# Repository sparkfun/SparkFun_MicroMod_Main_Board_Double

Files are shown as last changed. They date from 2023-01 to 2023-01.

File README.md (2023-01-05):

SparkFun MicroMod Main Board - Double
========================================

SparkFun MicroMod Main Board - Double (https://www.sparkfun.com/products/20595)

[*SparkFun MicroMod Main Board - Double (DEV-20595)*](https://www.sparkfun.com/products/20595)

The MicroMod Main Board - Double is a specialized carrier board that allows you to interface a MicroMod Processor Board with up to two MicroMod Function Boards. With the M.2 MicroMod connector, connecting your Processor and Function Boards is a breeze. Simply match up the key on your board's beveled edge connector to the key on the M.2 connector and secure the boards with screws.

The Double Main Board includes one USB-C connector for power and programming the Processor Board. A jumper is available on the back of the board to isolate the USB C's shield pin. Two buttons for reset and boot are also populated on the board. Processor Board pins are also broken out as 2x5 SWD pins. Also, included on the board is a 2A resettable fuse and 3.3V/1A voltage regulator. A second 3.3V/500mA voltage regulator is included on the board to power your Qwiic-enabled devices. We've even added convenient PTH jumpers for advanced users looking to bypass the fuse and measure the current consumption on the 5V and 3.3V lines for low-power testing. For those that need to go remote with their application, the board includes a 2-pin JST connector and a single-cell LiPo MCP73831 charge IC (set to a charge rate of 500mA).

Two switches have been included to toggle between the general-purpose pins and each Function Board's voltage regulator. A third switch has also been included to switch between different SPI chip select pins on the second Function Board. Four status LEDs are available for power and charging. These can also be disabled through the jumpers. There is a microSD card socket so you can also plug in a microSD card for data logging. The microSD socket can be disabled through the I/O pins. Finally, two Qwiic connectors are populated on the board with built-in pull-up resistors to easily add Qwiic-enabled I<sup>2</sup>C devices to your projects!

Repository Contents
-------------------

* **/Firmware** - Arduino example code from the tutorial
* **/Hardware** - Eagle design files (.brd, .sch)
* **/Production** - Production panel files (.brd)

Documentation
--------------

* **[Hookup Guide V2](https://learn.sparkfun.com/tutorials/2683)** - Basic hookup guide

Product Versions
----------------
* [DEV-20595](https://www.sparkfun.com/products/20595)- Initial release, v2.2
* [DEV-18576](https://www.sparkfun.com/products/18576)- Initial release, v1.1

Version History
---------------
* v2.2
* v1.1 - Initial Release

License Information
-------------------

This product is _**open source**_! 

Please review the LICENSE.md file for license information. 

If you have any questions or concerns on licensing, please contact technical support on our [SparkFun forums](https://forum.sparkfun.com/viewforum.php?f=152).

Distributed as-is; no warranty is given.

- Your friends at SparkFun.

_<COLLABORATION CREDIT>_

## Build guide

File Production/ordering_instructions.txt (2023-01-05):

panel size, 139x250mm
PCB thickness, 1.6mm
number of layers, 2
soldermask color, Red
silkscreen color, White
oz copper, 1oz
finish, HASL lead free
stencils, top
pcs per panel, 3
min trace width, 0.1778mm / 0.0070in
min drill size, 0.3048mm / 0.0120in

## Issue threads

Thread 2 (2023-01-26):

CAN-RX and CAN-TX Labels are reversed on MICROMOD_FUNCTION symbol

NPoole, 2023-01-26:
As it's currently labeled, this board appears to connect the processor board's CAN-RX to the function board's CAN-TX and vise versa, but this is incorrect. I've updated the library symbol in the Eagle library to fix the labels without changing the wiring. Next time this board gets revved, replace MICROMOD_FUNCTION_MAIN with the new version and replace pins "by coordinates" (not "by names") in order to ensure the schematic is fixed.

To reiterate, the correct connection scheme is TX-TX and RX-RX

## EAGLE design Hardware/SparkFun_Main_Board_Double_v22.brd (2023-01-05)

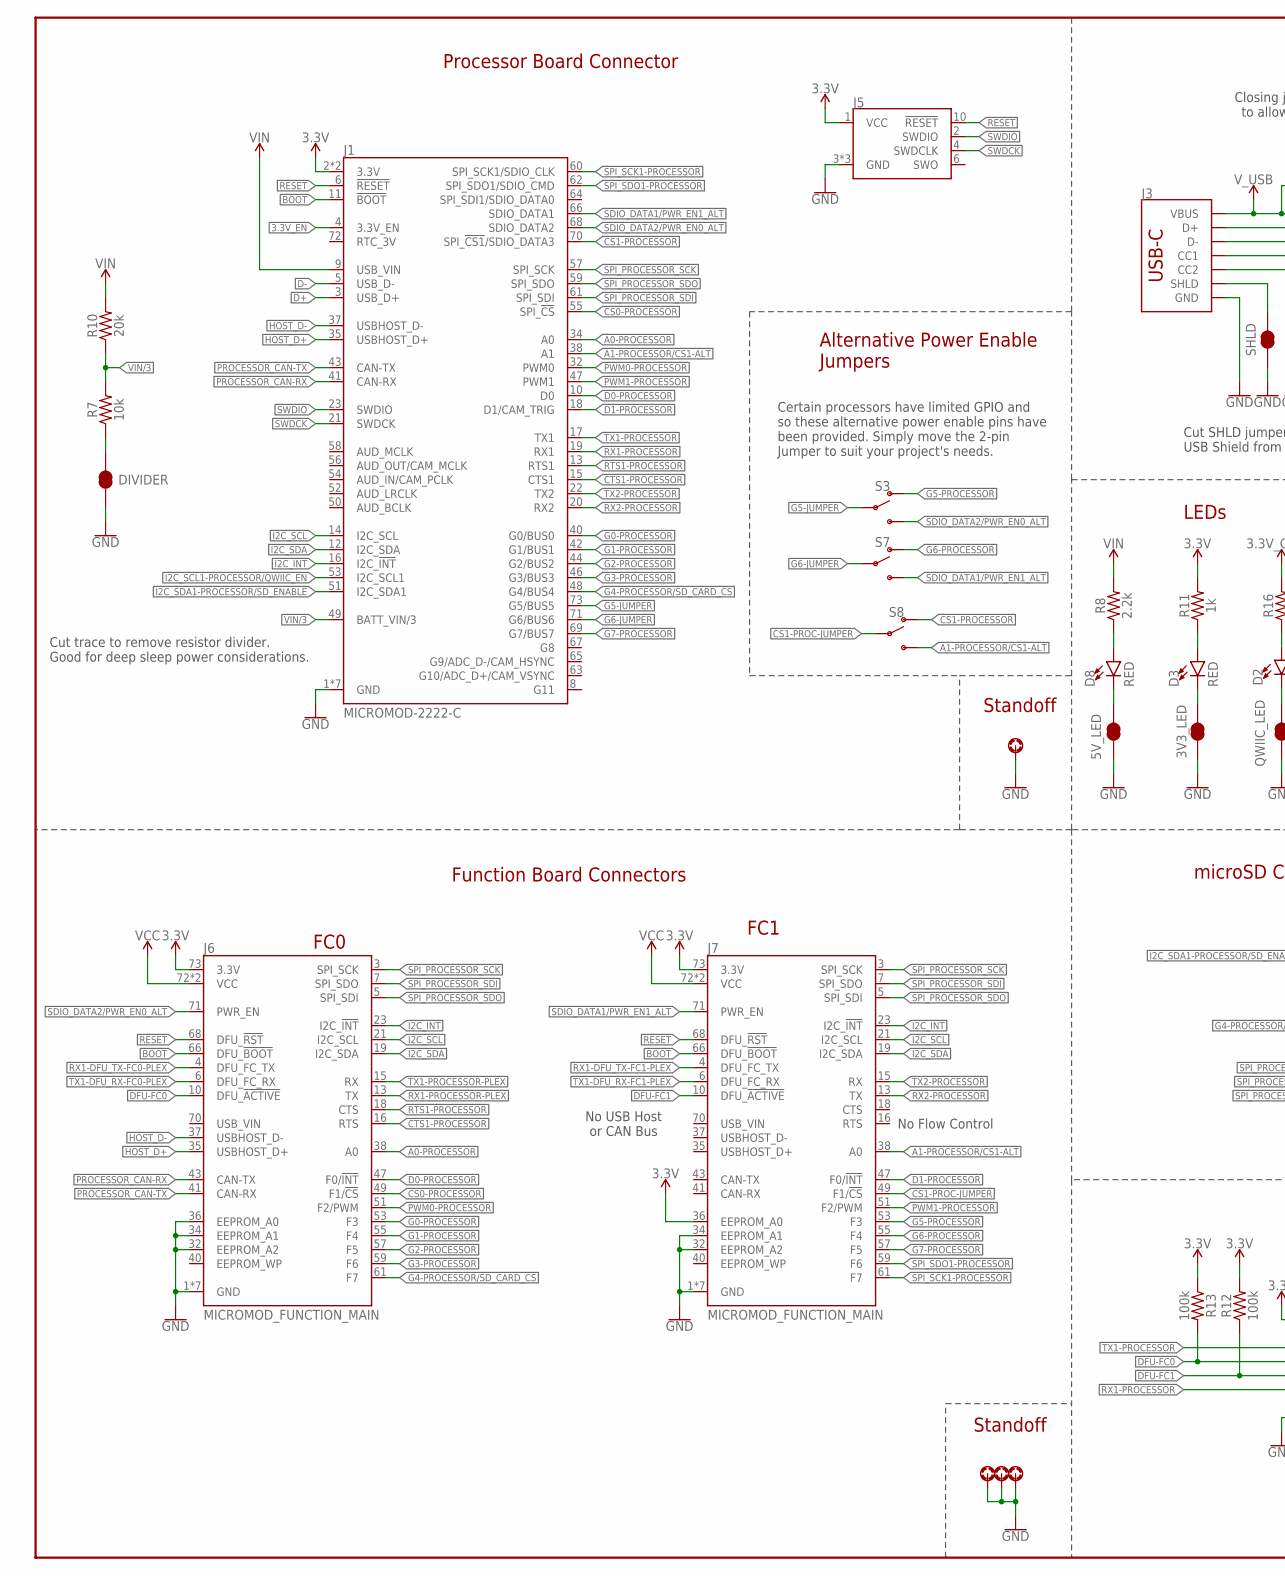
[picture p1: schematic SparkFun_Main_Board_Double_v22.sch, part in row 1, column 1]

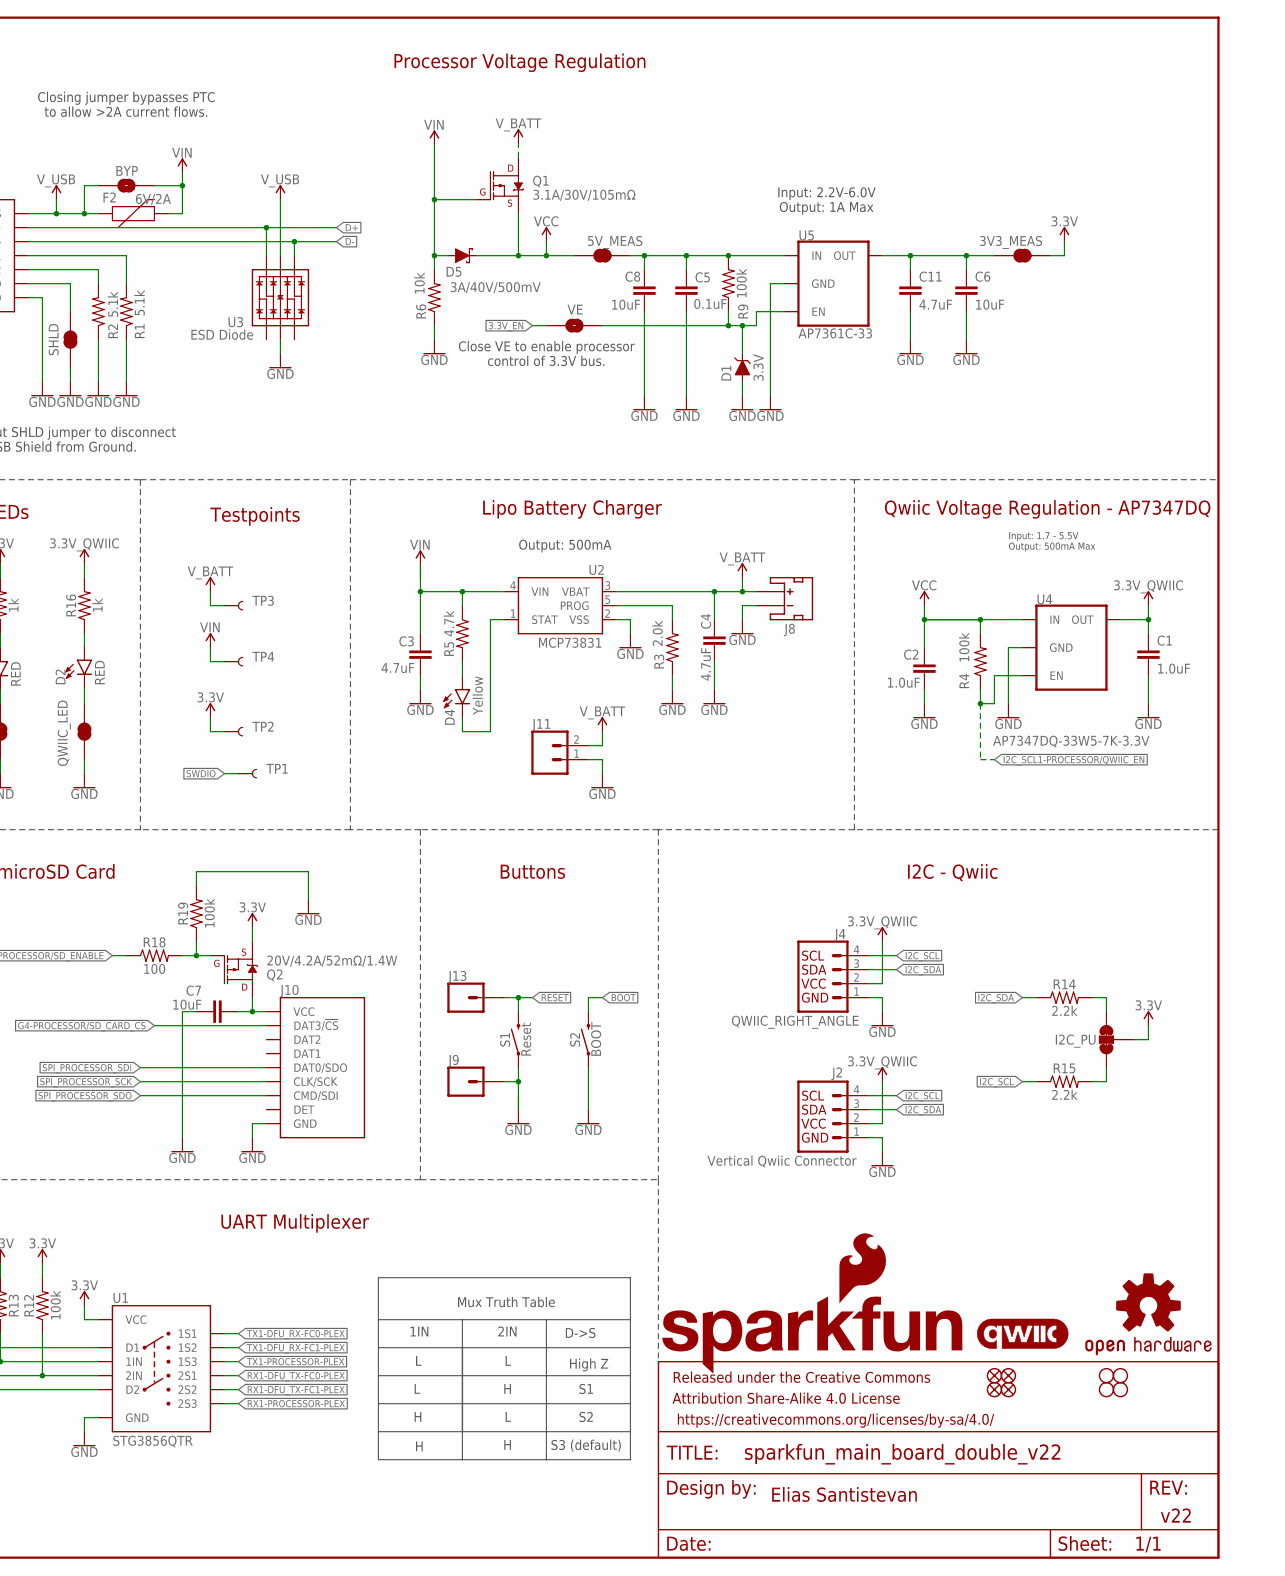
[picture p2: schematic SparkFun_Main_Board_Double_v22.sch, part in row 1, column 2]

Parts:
3V3_LED, 5V_LED: JUMPER-SMT_2_NC_TRACE_SILK; SMT-JUMPER_2_NC_TRACE_SILK
3V3_MEAS, 5V_MEAS: JUMPER-COMBO_2_NC_TRACE; COMBO-JUMPER_2_NC_TRACE
BYP: JUMPER-SMT_2_NO_SILK; SMT-JUMPER_2_NO_SILK
C1, C2: 1.0uF; 0603
C3, C4, C11: 4.7uF; 0603
C5: 0.1uF; 0603
C6, C8: 10uF; 0805
C7: 10uF; 0603
D1: 3.3V; SOD-323
D2, D3, D8: RED; LED-0603
D4: Yellow; LED-0603
D5: 3A/40V/500mV; SMA-DIODE
DIVIDER: JUMPER-SMT_2_NC_TRACE_SILK; SMT-JUMPER_2_NC_TRACE_SILK
F2: 6V/2A; 1210
FD1, FD2, FD3, FD4: FIDUCIAL1X2; FIDUCIAL-1X2
FRAME1: FRAME-LEDGER; CREATIVE_COMMONS
H2, H3, H4, H8: STAND-OFF-REFLOW-M2.5_2.5MM_TALL; STAND-OFF-REFLOW-M2.5
H14, H15, H16, H17: STAND-OFFTIGHT; STAND-OFF-TIGHT
I2C_PU: JUMPER-SMT_3_2-NC_TRACE_SILK; SMT-JUMPER_3_2-NC_TRACE_SILK
J1: MICROMOD-2222-C; M.2-CONNECTOR-E
J2: Vertical Qwiic Connector; JST04_1MM_VERT
J3: USB_C_2-LAYER_PADS; USB-C-16P-2LAYER-PADS
J4: QWIIC_RIGHT_ANGLE; JST04_1MM_RA
J5: CORTEX_JTAG_DEBUG_MINIMUM_PTH; 2X5-PTH-1.27MM
J6, J7: MICROMOD_FUNCTION_MAIN; M.2-CONNECTOR-E-FUNCTION-STANDARD
J8: JST_2MM_MALE; JST-2-SMD
J9, J13: CONN_01PTH_NO_SILK_YES_STOP; 1X01_NO_SILK
J10: MICRO-SD-PUSH-PUSH-EXT-PIN; MICROSD-EXTERNALPIN
J11: CONN_021X02_NO_SILK; 1X02_NO_SILK
LOGO1: QWIIC_LOGO_8MM; QWIIC_8MM
LOGO2: SFE_LOGO_NAME_FLAME.3_INCH; SFE_LOGO_NAME_FLAME_.3
LOGO3: OSHW-LOGOL; OSHW-LOGO-L
Q1: 3.1A/30V/105mΩ; SOT23-3
Q2: 20V/4.2A/52mΩ/1.4W; SOT23-3
QWIIC_LED: JUMPER-SMT_2_NC_TRACE_SILK; SMT-JUMPER_2_NC_TRACE_SILK
R1, R2: 5.1k; 0603
R3: 2.0k; 0603
R4, R9, R12, R13, R19: 100k; 0603
R5: 4.7k; 0603
R6, R7: 10k; 0603
R8, R14, R15: 2.2k; 0603
R10: 20k; 0603
R11, R16: 1k; 0603
R18: 100; 0603
S1: Reset; TACTILE_SWITCH_SMD_5.2MM
S2: BOOT; TACTILE_SWITCH_SMD_5.2MM
S3, S7, S8: SWITCH-SPDT-SMD-RIGHT-ANGLE; SWITCH_SPST_SMD_A
SHLD: JUMPER-SMT_2_NC_TRACE_SILK; SMT-JUMPER_2_NC_TRACE_SILK
TP1, TP2, TP3, TP4: TEST-POINT3X5; PAD.03X.05
U1: STG3856QTR; STG3856
U2: MCP73831; SOT23-5
U3: ESD Diode; SOT-23-6
U4: AP7347DQ-33W5-7K-3.3V; SOT25
U5: AP7361C-33; UDFN-8
VE: JUMPER-SMT_2_NO_SILK; SMT-JUMPER_2_NO_SILK

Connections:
3.3V: 3V3_MEAS.2, 3V3_MEAS.4 (2), I2C_PU.2, J1.2 (3.3V), J1.74 (3.3V), J5.1 (VCC), J6.73 (3.3V), J7.36 (EEPROM_A0), J7.73 (3.3V), Q2.2 (S), R11.2, R12.2, R13.1, TP2.1, U1.P11 (VCC)
3.3V_EN: J1.4 (3.3V_EN), VE.1
3.3V_EN_VE: D1.C, R9.1, U5.5 (EN), VE.2
3.3V_QWIIC: C1.1, J2.2, J4.2, R16.2, U4.5 (OUT)
3V3_MEAS: 3V3_MEAS.1, 3V3_MEAS.3 (1), C6.1, C11.1, U5.1 (OUT)
5V_MEAS: 5V_MEAS.2, 5V_MEAS.4 (2), C5.1, C8.1, R9.2, U5.8 (IN)
!BOOT!: J1.11 (!BOOT!), J6.66 (DFU_!BOOT!), J7.66 (DFU_!BOOT!), S2.3 (2), S2.4 (2)
!CS0!-PROCESSOR: J1.55 (SPI_!CS!), J6.49 (F1/!CS!)
!CS1!-PROC-JUMPER: J7.49 (F1/!CS!), S8.2
!CS1!-PROCESSOR: J1.70 (SPI_!CS1!/SDIO_DATA3), S8.1 (O)
!DFU-FC0!: J6.10 (DFU_!ACTIVE!), R13.2, U1.P12 (1IN)
!DFU-FC1!: J7.10 (DFU_!ACTIVE!), R12.1, U1.P10 (2IN)
!RESET!: J1.6 (!RESET!), J5.10 (!RESET), J6.68 (DFU_!RST!), J7.68 (DFU_!RST!), J13.1, S1.3 (2), S1.4 (2)
A0-PROCESSOR: J1.34 (A0), J6.38 (A0)
A1-PROCESSOR/!CS1!-ALT: J1.38 (A1), J7.38 (A0), S8.3 (S)
CTS1-PROCESSOR: J1.15 (CTS1), J6.16 (RTS)
D0-PROCESSOR: J1.10 (D0), J6.47 (F0/!INT!)
D1-PROCESSOR: J1.18 (D1/CAM_TRIG), J7.47 (F0/!INT!)
D+: J1.3 (USB_D+), J3.A6 (D+), J3.B6 (D+), U3.6 (IO4)
D-: J1.5 (USB_D-), J3.A7 (D-), J3.B7 (D-), U3.4 (IO3)
G0-PROCESSOR: J1.40 (G0/BUS0), J6.53 (F3)
G1-PROCESSOR: J1.42 (G1/BUS1), J6.55 (F4)
G2-PROCESSOR: J1.44 (G2/BUS2), J6.57 (F5)
G3-PROCESSOR: J1.46 (G3/BUS3), J6.59 (F6)
G4-PROCESSOR/SD_CARD_!CS!: J1.48 (G4/BUS4), J6.61 (F7), J10.2 (DAT3/!CS!)
G5-JUMPER: J1.73 (G5/BUS5), S3.2
G5-PROCESSOR: J7.53 (F3), S3.1 (O)
G6-JUMPER: J1.71 (G6/BUS6), S7.2
G6-PROCESSOR: J7.55 (F4), S7.1 (O)
G7-PROCESSOR: J1.69 (G7/BUS7), J7.57 (F5)
GND: 3V3_LED.1, 5V_LED.1, C1.2, C2.2, C3.2, C4.2, C5.2, C6.2, C7.1, C8.2, C11.2, D1.A, DIVIDER.1, H2.1, H3.1, H4.1, H8.1, J1.1 (GND), J1.7 (GND), J1.33 (GND), J1.36 (GND), J1.39 (GND), J1.45 (GND), J1.75 (GND), J2.1, J3.GND, J3.GND2 (GND), J4.1, J5.3 (GND), J5.5 (GND), J5.9 (GND), J6.1 (GND), J6.2 (GND), J6.8 (GND), J6.32 (EEPROM_A2), J6.33 (GND), J6.34 (EEPROM_A1), J6.36 (EEPROM_A0), J6.39 (GND), J6.45 (GND), J6.75 (GND), J7.1 (GND), J7.2 (GND), J7.8 (GND), J7.32 (EEPROM_A2), J7.33 (GND), J7.34 (EEPROM_A1), J7.39 (GND), J7.45 (GND), J7.75 (GND), J8.1 (-), J9.1, J10.6 (GND), J10.10 (GND), J10.11 (GND), J10.12 (GND), J10.13 (GND), J11.1, QWIIC_LED.1, R1.1, R2.1, R3.1, R6.1, R19.2, S1.1, S1.2 (1), S2.1, S2.2 (1), SHLD.1, U1.P5 (GND), U2.2 (VSS), U3.2 (VSS), U4.2 (GND), U5.4 (GND), U5.EP (GND)
HOST_D+: J1.35 (USBHOST_D+), J6.35 (USBHOST_D+)
HOST_D-: J1.37 (USBHOST_D-), J6.37 (USBHOST_D-)
I2C_!INT!: J1.16 (I2C_!INT!), J6.23 (I2C_!INT!), J7.23 (I2C_!INT!)
I2C_SCL: J1.14 (I2C_SCL), J2.4, J4.4, J6.21 (I2C_SCL), J7.21 (I2C_SCL), R15.1
I2C_SCL1-PROCESSOR/QWIIC_EN: J1.53 (I2C_SCL1), R4.1, U4.3 (EN)
I2C_SDA: J1.12 (I2C_SDA), J2.3, J4.3, J6.19 (I2C_SDA), J7.19 (I2C_SDA), R14.1
I2C_SDA1-PROCESSOR/!SD_ENABLE!: J1.51 (I2C_SDA1), R18.1
unnamed: D4.A, R5.2
unnamed: 5V_LED.2, D8.C
unnamed: D3.A, R11.1
unnamed: J3.B5 (CC2), R2.2
unnamed: J3.A5 (CC1), R1.2
unnamed: R3.2, U2.5 (PROG)
unnamed: DIVIDER.2, R7.1
unnamed: D2.C, QWIIC_LED.2
unnamed: D2.A, R16.1
unnamed: 3V3_LED.2, D3.C
unnamed: I2C_PU.3, R14.2
unnamed: D8.A, R8.1
unnamed: I2C_PU.1, R15.2
unnamed: D4.C, U2.1 (STAT)
unnamed: C7.2, J10.4 (VCC), Q2.3 (D)
unnamed: Q2.1 (G), R18.2, R19.1
PROCESSOR_CAN-RX: J1.41 (CAN-RX), J6.43 (CAN-TX)
PROCESSOR_CAN-TX: J1.43 (CAN-TX), J6.41 (CAN-RX)
PWM0-PROCESSOR: J1.32 (PWM0), J6.51 (F2/PWM)
PWM1-PROCESSOR: J1.47 (PWM1), J7.51 (F2/PWM)
RTS1-PROCESSOR: J1.13 (RTS1), J6.18 (CTS)
RX1-DFU_TX-FC0-PLEX: J6.4 (DFU_FC_TX), U1.P9 (2S1)
RX1-DFU_TX-FC1-PLEX: J7.4 (DFU_FC_TX), U1.P8 (2S2)
RX1-PROCESSOR: J1.19 (RX1), U1.P6 (D2)
RX1-PROCESSOR-PLEX: J6.13 (TX), U1.P7 (2S3)
RX2-PROCESSOR: J1.20 (RX2), J7.13 (TX)
SDIO_DATA1/PWR_EN1_ALT: J1.66 (SDIO_DATA1), J7.71 (PWR_EN), S7.3 (S)
SDIO_DATA2/PWR_EN0_ALT: J1.68 (SDIO_DATA2), J6.71 (PWR_EN), S3.3 (S)
SHLD: J3.SHLD1 (SHLD), J3.SHLD2 (SHLD), J3.SHLD3 (SHLD), J3.SHLD4 (SHLD), SHLD.2
SPI_PROCESSOR_SCK: J1.57 (SPI_SCK), J6.3 (SPI_SCK), J7.3 (SPI_SCK), J10.5 (CLK/SCK)
SPI_PROCESSOR_SDI: J1.61 (SPI_SDI), J6.7 (SPI_SDO), J7.7 (SPI_SDO), J10.7 (DAT0/SDO)
SPI_PROCESSOR_SDO: J1.59 (SPI_SDO), J6.5 (SPI_SDI), J7.5 (SPI_SDI), J10.3 (CMD/SDI)
SPI_SCK1-PROCESSOR: J1.60 (SPI_SCK1/SDIO_CLK), J7.61 (F7)
SPI_SDO1-PROCESSOR: J1.62 (SPI_SDO1/SDIO_CMD), J7.59 (F6)
SWDCK: J1.21 (SWDCK), J5.4 (SWDCLK)
SWDIO: J1.23 (SWDIO), J5.2 (SWDIO), TP1.1
TX1-DFU_RX-FC0-PLEX: J6.6 (DFU_FC_RX), U1.P1 (1S1)
TX1-DFU_RX-FC1-PLEX: J7.6 (DFU_FC_RX), U1.P2 (1S2)
TX1-PROCESSOR: J1.17 (TX1), U1.P4 (D1)
TX1-PROCESSOR-PLEX: J6.15 (RX), U1.P3 (1S3)
TX2-PROCESSOR: J1.22 (TX2), J7.15 (RX)
VCC: 5V_MEAS.1, 5V_MEAS.3 (1), C2.1, D5.C, J6.72 (VCC), J6.74 (VCC), J7.72 (VCC), J7.74 (VCC), Q1.2 (S), R4.2, U4.1 (IN)
VIN: BYP.2, C3.1, D5.A, F2.2, J1.9 (USB_VIN), Q1.1 (G), R5.1, R6.2, R8.2, R10.2, TP4.1, U2.4 (VIN)
VIN/3: J1.49 (BATT_VIN/3), R7.2, R10.1
V_BATT: C4.1, J8.2 (+), J11.2, Q1.3 (D), TP3.1, U2.3 (VBAT)
V_USB: BYP.1, F2.1, J3.VBUS1 (VBUS), J3.VBUS2 (VBUS), U3.5 (VCC)

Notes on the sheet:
Function Board Connectors
Processor Board Connector
v22
microSD Card
I2C - Qwiic
FC0
FC1
No USB Host or CAN Bus
No Flow Control
Lipo Battery Charger
Testpoints
Processor Voltage Regulation
Closing jumper bypasses PTC to allow >2A current flows.
Input: 2.2V-6.0V Output: 1A Max
Close VE to enable processor control of 3.3V bus.
LEDs
Buttons
Elias Santistevan
Standoff
Alternative Power Enable Jumpers
Certain processors have limited GPIO and so these alternative power enable pins have been provided. Simply move the 2-pin Jumper to suit your project's needs.
Mux Truth Table
1IN
2IN
D->S
High Z
S3 (default)
UART Multiplexer
Qwiic Voltage Regulation - AP7347DQ
Input: 1.7 - 5.5V Output: 500mA Max
Output: 500mA
Cut SHLD jumper to disconnect USB Shield from Ground.
Cut trace to remove resistor divider. Good for deep sleep power considerations.

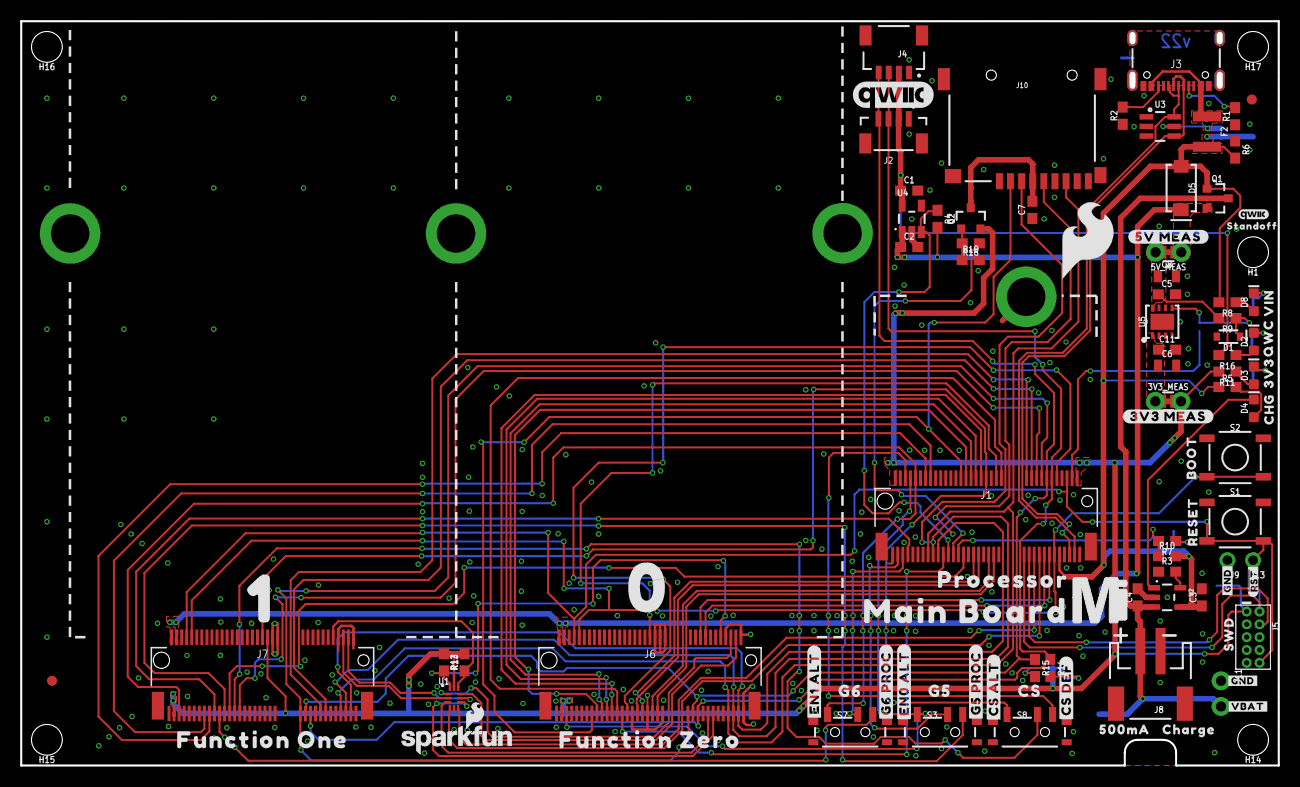
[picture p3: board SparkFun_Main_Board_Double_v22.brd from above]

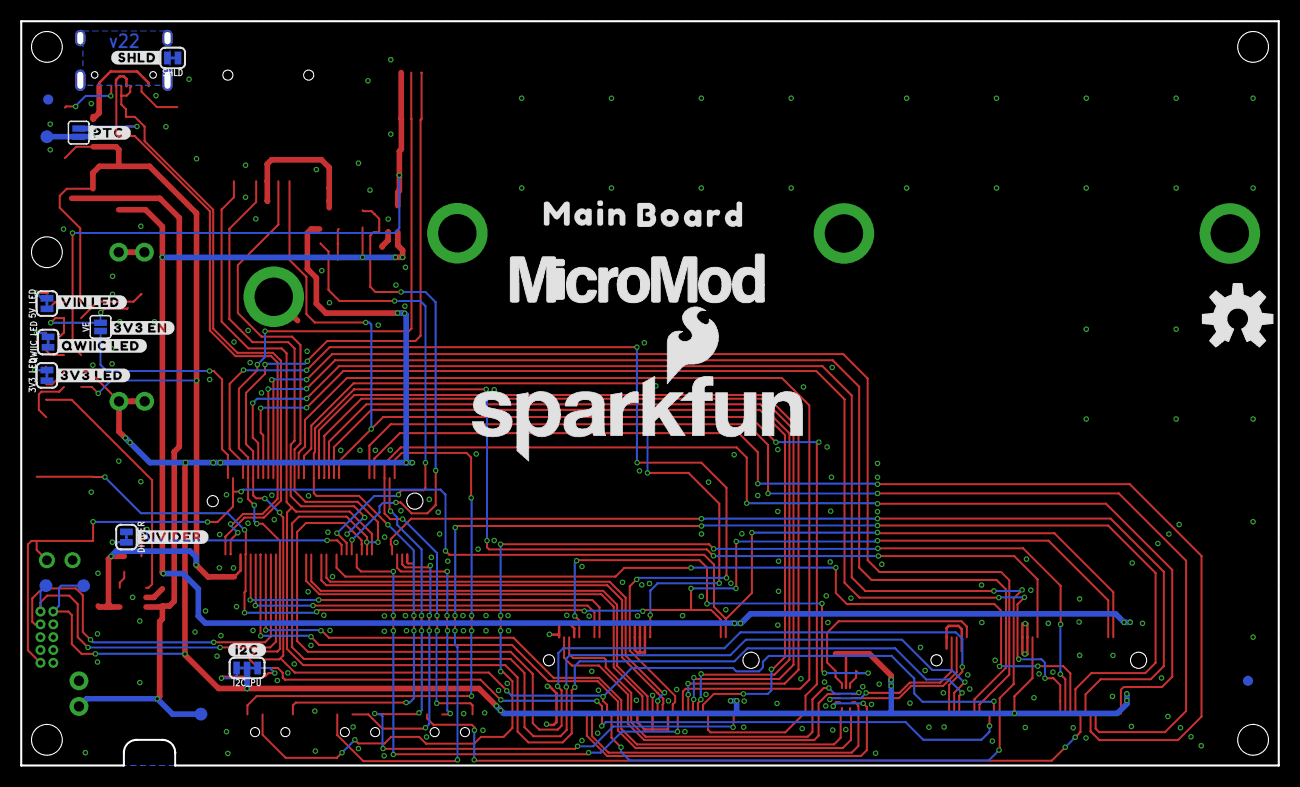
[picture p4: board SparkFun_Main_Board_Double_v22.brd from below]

Board: 2 copper layers, 124.5 x 73.7 mm, 136 parts (27 on the bottom side), 84 nets.

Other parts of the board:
FRAME2: FRAME-LEDGERNO_FOOTPRINT; DUMMY
H1: STAND-OFFTIGHT; STAND-OFF-TIGHT
U$1: #3V3_LED#22
U$2: #3V3_EN#23
U$3: ##RST##8
U$4: 3V332533
U$5: VIN32532
U$6: CHG32531
U$7: #SHLD#501
U$8: BOOT32541
U$9: RESET32540
U$10: PROCESSOR525
U$11: FUNCTION_ZERO520
U$12: FUNCTION_ONE524
U$13: MAIN523
U$14: MICROMOD_MI_LOGO_1
U$15: 0523
U$16: 1524
U$17: MICROMOD_LOGO_1
U$18: BOARD524
U$19: G518
U$20: #CS_ALT#20
U$21: MAIN_BOARD5523
U$22: QWIIC_3MM
U$23: STANDOFF501
U$24: SFE_LOGO_FLAME_.3
U$25: SWD6522
U$26: #3V3_MEAS#6522
U$27: CHARGE501
U$28: #QWIIC_LED#22
U$29: G6519
U$30: #I2C#501
U$31: #5V_MEAS#6522
U$32: CS17
U$33: 500MA6520
U$34: #CS_DEF#19
U$35: #G5_PROC#21
U$36: #G6_PROC#21
U$37: #EN0_ALT#21
U$38: #EN1_ALT#21
U$39, U$40: #GND#10
U$41: #DIVIDER#23
U$42: #VIN_LED#24
U$43: QWC18
U$44: SFE_LOGO_NAME_FLAME_.1
U$45: #PTC#13
U$46: #VBAT#9

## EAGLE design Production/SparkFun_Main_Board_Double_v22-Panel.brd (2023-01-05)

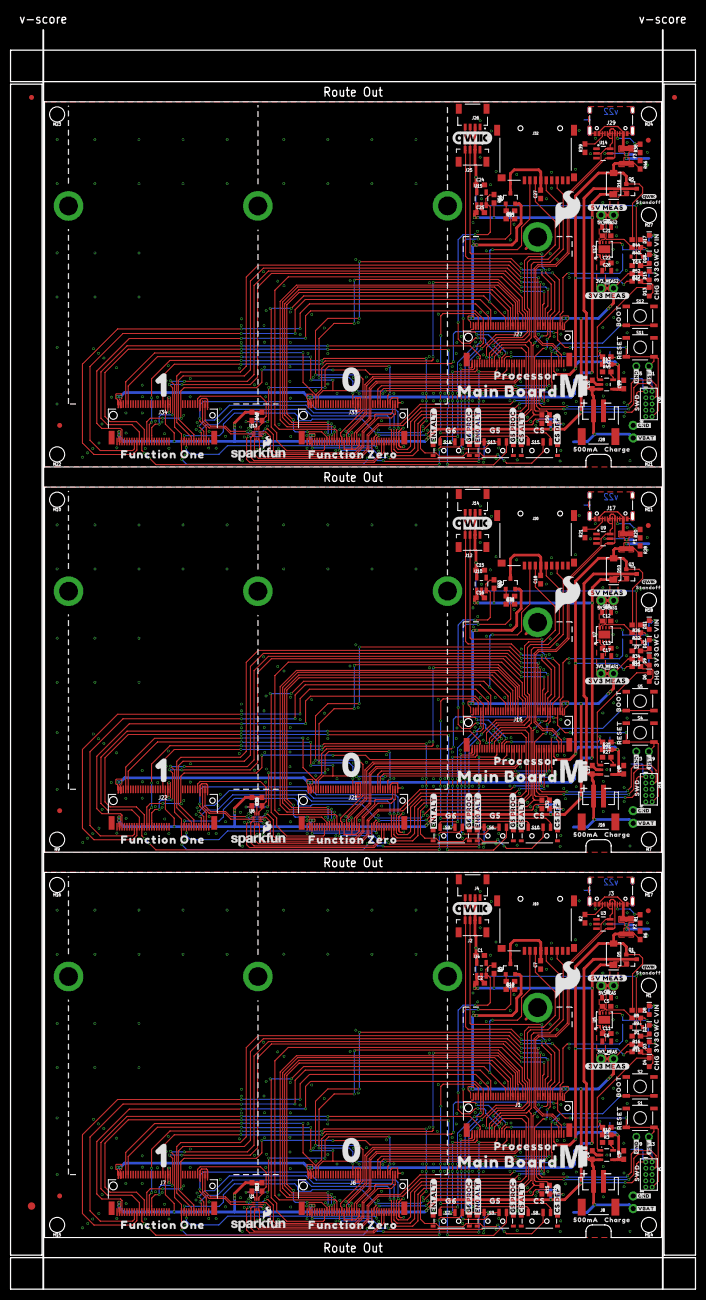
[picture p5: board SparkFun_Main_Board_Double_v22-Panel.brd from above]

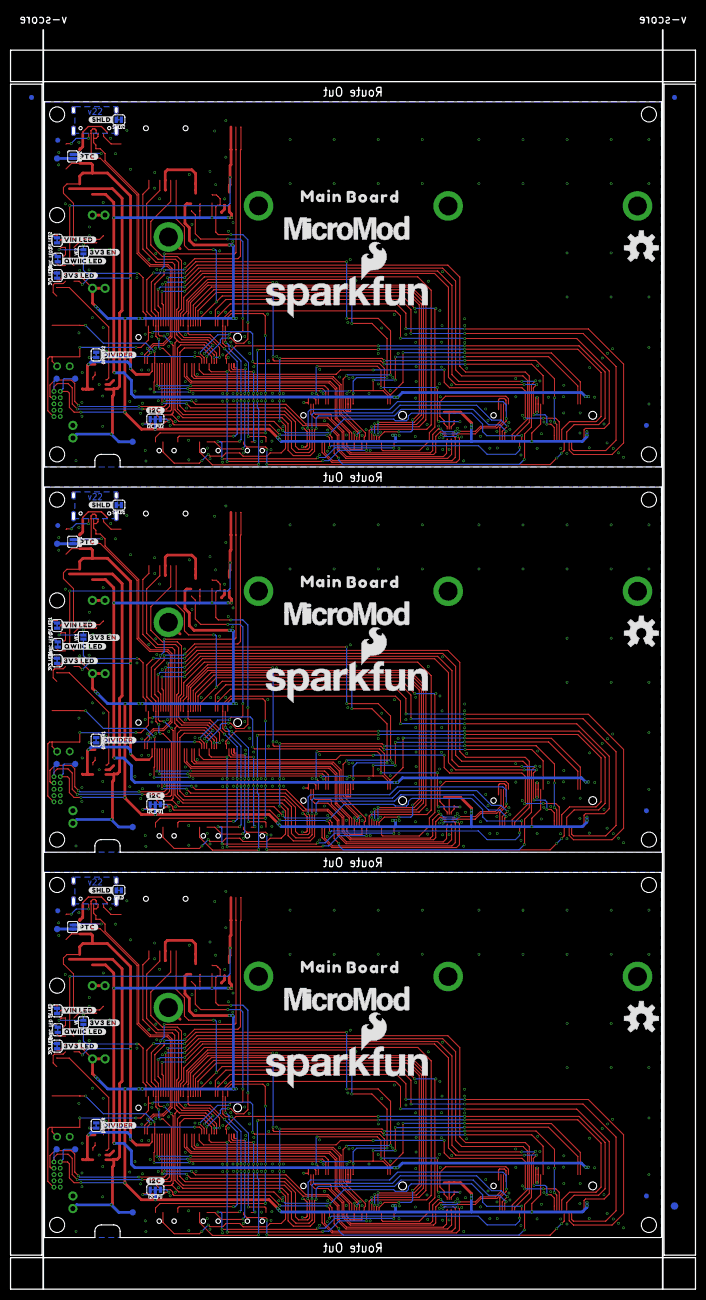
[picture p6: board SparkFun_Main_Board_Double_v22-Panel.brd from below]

Board: 2 copper layers, 138.2 x 254.0 mm, 408 parts (84 on the bottom side), 252 nets.

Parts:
3V3_LED, 3V3_LED1, 3V3_LED2, 5V_LED, 5V_LED1, 5V_LED2: JUMPER-SMT_2_NC_TRACE_SILK; SMT-JUMPER_2_NC_TRACE_SILK
3V3_MEAS, 3V3_MEAS1, 3V3_MEAS2, 5V_MEAS, 5V_MEAS1, 5V_MEAS2: JUMPER-COMBO_2_NC_TRACE; COMBO-JUMPER_2_NC_TRACE
BYP, BYP1, BYP2: JUMPER-SMT_2_NO_SILK; SMT-JUMPER_2_NO_SILK
C1, C2, C15, C16, C24, C25: 1.0uF; 0603
C3, C4, C9, C10, C11, C13, C19, C20, C22: 4.7uF; 0603
C5, C12, C21: 0.1uF; 0603
C6, C8, C14, C17, C23, C26: 10uF; 0805
C7, C18, C27: 10uF; 0603
D1, D7, D14: 3.3V; SOD-323
D2, D3, D8, D9, D11, D12, D15, D17, D18: RED; LED-0603
D4, D6, D13: Yellow; LED-0603
D5, D10, D16: 3A/40V/500mV; SMA-DIODE
DIVIDER, DIVIDER1, DIVIDER2: JUMPER-SMT_2_NC_TRACE_SILK; SMT-JUMPER_2_NC_TRACE_SILK
E$1, E$2, E$3, E$4: FIDUCIAL-1X2
E$5, E$6: FIDUCIAL-1.5X3
F1, F2, F3: 6V/2A; 1210
FD1, FD2, FD3, FD4, FD5, FD6, FD7, FD8, FD9, FD10, FD11, FD12: FIDUCIAL1X2; FIDUCIAL-1X2
H1, H7, H9, H10, H11, H14, H15, H16, H17, H18, H21, H22, H23, H24, H27: STAND-OFFTIGHT; STAND-OFF-TIGHT
H2, H3, H4, H5, H6, H8, H12, H13, H19, H20, H25, H26: STAND-OFF-REFLOW-M2.5_2.5MM_TALL; STAND-OFF-REFLOW-M2.5
I2C_PU, I2C_PU1, I2C_PU2: JUMPER-SMT_3_2-NC_TRACE_SILK; SMT-JUMPER_3_2-NC_TRACE_SILK
J1, J15, J27: MICROMOD-2222-C; M.2-CONNECTOR-E
J2, J12, J25: Vertical Qwiic Connector; JST04_1MM_VERT
J3, J17, J29: USB-C-16P-2LAYER-PADS
J4, J14, J26: QWIIC_RIGHT_ANGLE; JST04_1MM_RA
J5, J18, J30: CORTEX_JTAG_DEBUG_MINIMUM_PTH; 2X5-PTH-1.27MM
J6, J7, J21, J22, J33, J34: MICROMOD_FUNCTION_MAIN; M.2-CONNECTOR-E-FUNCTION-STANDARD
J8, J16, J28: JST-2-SMD
J9, J13, J19, J23, J31, J35: 1X01_NO_SILK
J10, J20, J32: MICRO-SD-PUSH-PUSH-EXT-PIN; MICROSD-EXTERNALPIN
J11, J24, J36: 1X02_NO_SILK
LOGO1, LOGO4, LOGO7: QWIIC_LOGO_8MM; QWIIC_8MM
LOGO2, LOGO5, LOGO8: SFE_LOGO_NAME_FLAME.3_INCH; SFE_LOGO_NAME_FLAME_.3
LOGO3, LOGO6, LOGO9: OSHW-LOGOL; OSHW-LOGO-L
Q1, Q3, Q5: 3.1A/30V/105mΩ; SOT23-3
Q2, Q4, Q6: 20V/4.2A/52mΩ/1.4W; SOT23-3
QWIIC_LED, QWIIC_LED1, QWIIC_LED2: JUMPER-SMT_2_NC_TRACE_SILK; SMT-JUMPER_2_NC_TRACE_SILK
R1, R2, R20, R21, R38, R39: 5.1k; 0603
R3, R27, R45: 2.0k; 0603
R4, R9, R12, R13, R19, R22, R29, R30, R33, R36, R40, R47, R48, R51, R54: 100k; 0603
R5, R17, R37: 4.7k; 0603
R6, R7, R24, R28, R42, R46: 10k; 0603
R8, R14, R15, R26, R31, R32, R44, R49, R50: 2.2k; 0603
R10, R25, R43: 20k; 0603
R11, R16, R23, R34, R41, R52: 1k; 0603
R18, R35, R53: 100; 0603
S1, S4, S11: Reset; TACTILE_SWITCH_SMD_5.2MM
S2, S5, S12: BOOT; TACTILE_SWITCH_SMD_5.2MM
S3, S6, S7, S8, S9, S10, S13, S14, S15: SWITCH_SPST_SMD_A
SHLD, SHLD1, SHLD2: JUMPER-SMT_2_NC_TRACE_SILK; SMT-JUMPER_2_NC_TRACE_SILK
TP1, TP2, TP3, TP4, TP5, TP6, TP7, TP8, TP9, TP10, TP11, TP12: TEST-POINT3X5; PAD.03X.05
U1, U8, U13: STG3856QTR; STG3856
U2, U6, U11: MCP73831; SOT23-5
U3, U9, U14: ESD Diode; SOT-23-6
U4, U10, U15: AP7347DQ-33W5-7K-3.3V; SOT25
U5, U7, U12: AP7361C-33; UDFN-8
U$1, U$82, U$128: #3V3_LED#22
U$2, U$81, U$127: #3V3_EN#23
U$3, U$89, U$135: ##RST##8
U$4, U$47, U$93: 3V332533
U$5, U$48, U$94: VIN32532
U$6, U$49, U$95: CHG32531
U$7, U$72, U$118: #SHLD#501
U$8, U$50, U$96: BOOT32541
U$9, U$51, U$97: RESET32540
U$10, U$52, U$98: PROCESSOR525
U$11, U$53, U$99: FUNCTION_ZERO520
U$12, U$54, U$100: FUNCTION_ONE524
U$13, U$58, U$104: MAIN523
U$14, U$55, U$101: MICROMOD_MI_LOGO_1
U$15, U$56, U$102: 0523
U$16, U$57, U$103: 1524
U$17, U$61, U$107: MICROMOD_LOGO_1
U$18, U$59, U$105: BOARD524
U$19, U$77, U$123: G518
U$20, U$65, U$111: #CS_ALT#20
U$21, U$60, U$106: MAIN_BOARD5523
U$22, U$62, U$108: QWIIC_3MM
U$23, U$63, U$109: STANDOFF501
U$24, U$64, U$110: SFE_LOGO_FLAME_.3
U$25, U$80, U$126: SWD6522
U$26, U$74, U$120: #3V3_MEAS#6522
U$27, U$71, U$117: CHARGE501
U$28, U$83, U$129: #QWIIC_LED#22
U$29, U$78, U$124: G6519
U$30, U$73, U$119: #I2C#501
U$31, U$75, U$121: #5V_MEAS#6522
U$32, U$79, U$125: CS17
U$33, U$76, U$122: 500MA6520
U$34, U$66, U$112: #CS_DEF#19
U$35, U$67, U$113: #G5_PROC#21
U$36, U$68, U$114: #G6_PROC#21
U$37, U$69, U$115: #EN0_ALT#21
U$38, U$70, U$116: #EN1_ALT#21
U$39, U$40, U$90, U$91, U$136, U$137: #GND#10
U$41, U$84, U$130: #DIVIDER#23
U$42, U$85, U$131: #VIN_LED#24
U$43, U$86, U$132: QWC18
U$44, U$87, U$133: SFE_LOGO_NAME_FLAME_.1
U$45, U$88, U$134: #PTC#13
U$46, U$92, U$138: #VBAT#9
VE, VE1, VE2: JUMPER-SMT_2_NO_SILK; SMT-JUMPER_2_NO_SILK

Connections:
3.3V: 3V3_MEAS.2, 3V3_MEAS.4, I2C_PU.2, J1.2, J1.74, J5.1, J6.73, J7.36, J7.73, Q2.2, R11.2, R12.2, R13.1, TP2.1, U1.P11
3.3V1: 3V3_MEAS1.2, 3V3_MEAS1.4, I2C_PU1.2, J15.2, J15.74, J18.1, J21.73, J22.36, J22.73, Q4.2, R23.2, R29.2, R30.1, TP5.1, U8.P11
3.3V2: 3V3_MEAS2.2, 3V3_MEAS2.4, I2C_PU2.2, J27.2, J27.74, J30.1, J33.73, J34.36, J34.73, Q6.2, R41.2, R47.2, R48.1, TP9.1, U13.P11
3.3V_EN: J1.4, VE.1
3.3V_EN1: J15.4, VE1.1
3.3V_EN2: J27.4, VE2.1
3.3V_EN_VE: D1.C, R9.1, U5.5, VE.2
3.3V_EN_VE1: D7.C, R22.1, U7.5, VE1.2
3.3V_EN_VE2: D14.C, R40.1, U12.5, VE2.2
3.3V_QWIIC: C1.1, J2.2, J4.2, R16.2, U4.5
3.3V_QWIIC1: C15.1, J12.2, J14.2, R34.2, U10.5
3.3V_QWIIC2: C24.1, J25.2, J26.2, R52.2, U15.5
3V3_MEAS: 3V3_MEAS.1, 3V3_MEAS.3, C6.1, C11.1, U5.1
3V3_MEAS1: 3V3_MEAS1.1, 3V3_MEAS1.3, C13.1, C17.1, U7.1
3V3_MEAS2: 3V3_MEAS2.1, 3V3_MEAS2.3, C22.1, C26.1, U12.1
5V_MEAS: 5V_MEAS.2, 5V_MEAS.4, C5.1, C8.1, R9.2, U5.8
5V_MEAS1: 5V_MEAS1.2, 5V_MEAS1.4, C12.1, C14.1, R22.2, U7.8
5V_MEAS2: 5V_MEAS2.2, 5V_MEAS2.4, C21.1, C23.1, R40.2, U12.8
!BOOT!: J1.11, J6.66, J7.66, S2.3, S2.4
!BOOT!1: J15.11, J21.66, J22.66, S5.3, S5.4
!BOOT!2: J27.11, J33.66, J34.66, S12.3, S12.4
!CS0!-PROCESSOR: J1.55, J6.49
!CS0!-PROCESSOR1: J15.55, J21.49
!CS0!-PROCESSOR2: J27.55, J33.49
!CS1!-PROC-JUMPER: J7.49, S8.2
!CS1!-PROC-JUMPER1: J22.49, S10.2
!CS1!-PROC-JUMPER2: J34.49, S15.2
!CS1!-PROCESSOR: J1.70, S8.1
!CS1!-PROCESSOR1: J15.70, S10.1
!CS1!-PROCESSOR2: J27.70, S15.1
!DFU-FC0!: J6.10, R13.2, U1.P12
!DFU-FC0!1: J21.10, R30.2, U8.P12
!DFU-FC0!2: J33.10, R48.2, U13.P12
!DFU-FC1!: J7.10, R12.1, U1.P10
!DFU-FC1!1: J22.10, R29.1, U8.P10
!DFU-FC1!2: J34.10, R47.1, U13.P10
!RESET!: J1.6, J5.10, J6.68, J7.68, J13.1, S1.3, S1.4
!RESET!1: J15.6, J18.10, J19.1, J21.68, J22.68, S4.3, S4.4
!RESET!2: J27.6, J30.10, J31.1, J33.68, J34.68, S11.3, S11.4
A0-PROCESSOR: J1.34, J6.38
A0-PROCESSOR1: J15.34, J21.38
A0-PROCESSOR2: J27.34, J33.38
A1-PROCESSOR/!CS1!-ALT: J1.38, J7.38, S8.3
A1-PROCESSOR/!CS1!-ALT1: J15.38, J22.38, S10.3
A1-PROCESSOR/!CS1!-ALT2: J27.38, J34.38, S15.3
CTS1-PROCESSOR: J1.15, J6.16
CTS1-PROCESSOR1: J15.15, J21.16
CTS1-PROCESSOR2: J27.15, J33.16
D0-PROCESSOR: J1.10, J6.47
D0-PROCESSOR1: J15.10, J21.47
D0-PROCESSOR2: J27.10, J33.47
D1-PROCESSOR: J1.18, J7.47
D1-PROCESSOR1: J15.18, J22.47
D1-PROCESSOR2: J27.18, J34.47
D+: J1.3, J3.A6, J3.B6, U3.6
D+1: J15.3, J17.A6, J17.B6, U9.6
D+2: J27.3, J29.A6, J29.B6, U14.6
D-: J1.5, J3.A7, J3.B7, U3.4
D-1: J15.5, J17.A7, J17.B7, U9.4
D-2: J27.5, J29.A7, J29.B7, U14.4
G0-PROCESSOR: J1.40, J6.53
G0-PROCESSOR1: J15.40, J21.53
G0-PROCESSOR2: J27.40, J33.53
G1-PROCESSOR: J1.42, J6.55
G1-PROCESSOR1: J15.42, J21.55
G1-PROCESSOR2: J27.42, J33.55
G2-PROCESSOR: J1.44, J6.57
G2-PROCESSOR1: J15.44, J21.57
G2-PROCESSOR2: J27.44, J33.57
G3-PROCESSOR: J1.46, J6.59
G3-PROCESSOR1: J15.46, J21.59
G3-PROCESSOR2: J27.46, J33.59
G4-PROCESSOR/SD_CARD_!CS!: J1.48, J6.61, J10.2
G4-PROCESSOR/SD_CARD_!CS!1: J15.48, J20.2, J21.61
G4-PROCESSOR/SD_CARD_!CS!2: J27.48, J32.2, J33.61
G5-JUMPER: J1.73, S3.2
G5-JUMPER1: J15.73, S6.2
G5-JUMPER2: J27.73, S13.2
G5-PROCESSOR: J7.53, S3.1
G5-PROCESSOR1: J22.53, S6.1
G5-PROCESSOR2: J34.53, S13.1
G6-JUMPER: J1.71, S7.2
G6-JUMPER1: J15.71, S9.2
G6-JUMPER2: J27.71, S14.2
G6-PROCESSOR: J7.55, S7.1
G6-PROCESSOR1: J22.55, S9.1
G6-PROCESSOR2: J34.55, S14.1
G7-PROCESSOR: J1.69, J7.57
G7-PROCESSOR1: J15.69, J22.57
G7-PROCESSOR2: J27.69, J34.57
GND: 3V3_LED.1, 5V_LED.1, C1.2, C2.2, C3.2, C4.2, C5.2, C6.2, C7.1, C8.2, C11.2, D1.A, DIVIDER.1, H2.1, H3.1, H4.1, H8.1, J1.1, J1.7, J1.33, J1.36, J1.39, J1.45, J1.75, J2.1, J3.GND, J3.GND2, J4.1, J5.3, J5.5, J5.9, J6.1, J6.2, J6.8, J6.32, J6.33, J6.34, J6.36, J6.39, J6.45, J6.75, J7.1, J7.2, J7.8, J7.32, J7.33, J7.34, J7.39, J7.45, J7.75, J8.1, J9.1, J10.6, J10.10, J10.11, J10.12, J10.13, J11.1, QWIIC_LED.1, R1.1, R2.1, R3.1, R6.1, R19.2, S1.1, S1.2, S2.1, S2.2, SHLD.1, U1.P5, U2.2, U3.2, U4.2, U5.4, U5.EP
GND1: 3V3_LED1.1, 5V_LED1.1, C9.2, C10.2, C12.2, C13.2, C14.2, C15.2, C16.2, C17.2, C18.1, D7.A, DIVIDER1.1, H5.1, H6.1, H12.1, H13.1, J12.1, J14.1, J15.1, J15.7, J15.33, J15.36, J15.39, J15.45, J15.75, J16.1, J17.GND, J17.GND2, J18.3, J18.5, J18.9, J20.6, J20.10, J20.11, J20.12, J20.13, J21.1, J21.2, J21.8, J21.32, J21.33, J21.34, J21.36, J21.39, J21.45, J21.75, J22.1, J22.2, J22.8, J22.32, J22.33, J22.34, J22.39, J22.45, J22.75, J23.1, J24.1, QWIIC_LED1.1, R20.1, R21.1, R27.1, R28.1, R36.2, S4.1, S4.2, S5.1, S5.2, SHLD1.1, U6.2, U7.4, U7.EP, U8.P5, U9.2, U10.2
GND2: 3V3_LED2.1, 5V_LED2.1, C19.2, C20.2, C21.2, C22.2, C23.2, C24.2, C25.2, C26.2, C27.1, D14.A, DIVIDER2.1, H19.1, H20.1, H25.1, H26.1, J25.1, J26.1, J27.1, J27.7, J27.33, J27.36, J27.39, J27.45, J27.75, J28.1, J29.GND, J29.GND2, J30.3, J30.5, J30.9, J32.6, J32.10, J32.11, J32.12, J32.13, J33.1, J33.2, J33.8, J33.32, J33.33, J33.34, J33.36, J33.39, J33.45, J33.75, J34.1, J34.2, J34.8, J34.32, J34.33, J34.34, J34.39, J34.45, J34.75, J35.1, J36.1, QWIIC_LED2.1, R38.1, R39.1, R45.1, R46.1, R54.2, S11.1, S11.2, S12.1, S12.2, SHLD2.1, U11.2, U12.4, U12.EP, U13.P5, U14.2, U15.2
HOST_D+: J1.35, J6.35
HOST_D+1: J15.35, J21.35
HOST_D+2: J27.35, J33.35
HOST_D-: J1.37, J6.37
HOST_D-1: J15.37, J21.37
HOST_D-2: J27.37, J33.37
I2C_!INT!: J1.16, J6.23, J7.23
I2C_!INT!1: J15.16, J21.23, J22.23
I2C_!INT!2: J27.16, J33.23, J34.23
I2C_SCL: J1.14, J2.4, J4.4, J6.21, J7.21, R15.1
I2C_SCL1: J12.4, J14.4, J15.14, J21.21, J22.21, R32.1
I2C_SCL1-PROCESSOR/QWIIC_EN: J1.53, R4.1, U4.3
I2C_SCL1-PROCESSOR/QWIIC_EN1: J15.53, R33.1, U10.3
I2C_SCL1-PROCESSOR/QWIIC_EN2: J27.53, R51.1, U15.3
I2C_SCL2: J25.4, J26.4, J27.14, J33.21, J34.21, R50.1
I2C_SDA: J1.12, J2.3, J4.3, J6.19, J7.19, R14.1
I2C_SDA1: J12.3, J14.3, J15.12, J21.19, J22.19, R31.1
I2C_SDA1-PROCESSOR/!SD_ENABLE!: J1.51, R18.1
I2C_SDA1-PROCESSOR/!SD_ENABLE!1: J15.51, R35.1
I2C_SDA1-PROCESSOR/!SD_ENABLE!2: J27.51, R53.1
I2C_SDA2: J25.3, J26.3, J27.12, J33.19, J34.19, R49.1
unnamed: D4.A, R5.2
unnamed: 5V_LED.2, D8.C
unnamed: D3.A, R11.1
unnamed: J3.B5, R2.2
unnamed: J3.A5, R1.2
unnamed: R3.2, U2.5
unnamed: DIVIDER.2, R7.1
unnamed: D2.C, QWIIC_LED.2
unnamed: D2.A, R16.1
unnamed: 3V3_LED.2, D3.C
unnamed: I2C_PU.3, R14.2
unnamed: D8.A, R8.1
unnamed: I2C_PU.1, R15.2
unnamed: D4.C, U2.1
unnamed: D6.C, U6.1
unnamed: C7.2, J10.4, Q2.3
unnamed: J17.B5, R21.2
unnamed: Q2.1, R18.2, R19.1
unnamed: J17.A5, R20.2
unnamed: D9.A, R23.1
unnamed: D11.A, R26.1
unnamed: 5V_LED1.2, D11.C
unnamed: 3V3_LED1.2, D9.C
unnamed: I2C_PU1.3, R31.2
unnamed: I2C_PU1.1, R32.2
unnamed: R27.2, U6.5
unnamed: DIVIDER1.2, R24.1
unnamed: D12.C, QWIIC_LED1.2
unnamed: D12.A, R34.1
unnamed: C18.2, J20.4, Q4.3
unnamed: Q4.1, R35.2, R36.1
unnamed: D6.A, R17.2
unnamed: D13.C, U11.1
unnamed: J29.B5, R39.2
unnamed: J29.A5, R38.2
unnamed: D15.A, R41.1
unnamed: D17.A, R44.1
unnamed: 5V_LED2.2, D17.C
unnamed: 3V3_LED2.2, D15.C
unnamed: I2C_PU2.3, R49.2
unnamed: I2C_PU2.1, R50.2
unnamed: R45.2, U11.5
unnamed: DIVIDER2.2, R42.1
unnamed: D18.C, QWIIC_LED2.2
unnamed: D18.A, R52.1
unnamed: C27.2, J32.4, Q6.3
unnamed: Q6.1, R53.2, R54.1
unnamed: D13.A, R37.2
PROCESSOR_CAN-RX: J1.41, J6.43
PROCESSOR_CAN-RX1: J15.41, J21.43
PROCESSOR_CAN-RX2: J27.41, J33.43
PROCESSOR_CAN-TX: J1.43, J6.41
PROCESSOR_CAN-TX1: J15.43, J21.41
PROCESSOR_CAN-TX2: J27.43, J33.41
PWM0-PROCESSOR: J1.32, J6.51
PWM0-PROCESSOR1: J15.32, J21.51
PWM0-PROCESSOR2: J27.32, J33.51
PWM1-PROCESSOR: J1.47, J7.51
PWM1-PROCESSOR1: J15.47, J22.51
PWM1-PROCESSOR2: J27.47, J34.51
RTS1-PROCESSOR: J1.13, J6.18
RTS1-PROCESSOR1: J15.13, J21.18
RTS1-PROCESSOR2: J27.13, J33.18
RX1-DFU_TX-FC0-PLEX: J6.4, U1.P9
RX1-DFU_TX-FC0-PLEX1: J21.4, U8.P9
RX1-DFU_TX-FC0-PLEX2: J33.4, U13.P9
RX1-DFU_TX-FC1-PLEX: J7.4, U1.P8
RX1-DFU_TX-FC1-PLEX1: J22.4, U8.P8
RX1-DFU_TX-FC1-PLEX2: J34.4, U13.P8
RX1-PROCESSOR: J1.19, U1.P6
RX1-PROCESSOR1: J15.19, U8.P6
RX1-PROCESSOR2: J27.19, U13.P6
RX1-PROCESSOR-PLEX: J6.13, U1.P7
RX1-PROCESSOR-PLEX1: J21.13, U8.P7
RX1-PROCESSOR-PLEX2: J33.13, U13.P7
RX2-PROCESSOR: J1.20, J7.13
RX2-PROCESSOR1: J15.20, J22.13
RX2-PROCESSOR2: J27.20, J34.13
SDIO_DATA1/PWR_EN1_ALT: J1.66, J7.71, S7.3
SDIO_DATA1/PWR_EN1_ALT1: J15.66, J22.71, S9.3
SDIO_DATA1/PWR_EN1_ALT2: J27.66, J34.71, S14.3
SDIO_DATA2/PWR_EN0_ALT: J1.68, J6.71, S3.3
SDIO_DATA2/PWR_EN0_ALT1: J15.68, J21.71, S6.3
SDIO_DATA2/PWR_EN0_ALT2: J27.68, J33.71, S13.3
SHLD: J3.SHLD1, J3.SHLD2, J3.SHLD3, J3.SHLD4, SHLD.2
SHLD1: J17.SHLD1, J17.SHLD2, J17.SHLD3, J17.SHLD4, SHLD1.2
SHLD2: J29.SHLD1, J29.SHLD2, J29.SHLD3, J29.SHLD4, SHLD2.2
SPI_PROCESSOR_SCK: J1.57, J6.3, J7.3, J10.5
SPI_PROCESSOR_SCK1: J15.57, J20.5, J21.3, J22.3
SPI_PROCESSOR_SCK2: J27.57, J32.5, J33.3, J34.3
SPI_PROCESSOR_SDI: J1.61, J6.7, J7.7, J10.7
SPI_PROCESSOR_SDI1: J15.61, J20.7, J21.7, J22.7
SPI_PROCESSOR_SDI2: J27.61, J32.7, J33.7, J34.7
SPI_PROCESSOR_SDO: J1.59, J6.5, J7.5, J10.3
SPI_PROCESSOR_SDO1: J15.59, J20.3, J21.5, J22.5
SPI_PROCESSOR_SDO2: J27.59, J32.3, J33.5, J34.5
SPI_SCK1-PROCESSOR: J1.60, J7.61
SPI_SCK1-PROCESSOR1: J15.60, J22.61
SPI_SCK1-PROCESSOR2: J27.60, J34.61
SPI_SDO1-PROCESSOR: J1.62, J7.59
SPI_SDO1-PROCESSOR1: J15.62, J22.59
SPI_SDO1-PROCESSOR2: J27.62, J34.59
SWDCK: J1.21, J5.4
SWDCK1: J15.21, J18.4
SWDCK2: J27.21, J30.4
SWDIO: J1.23, J5.2, TP1.1
SWDIO1: J15.23, J18.2, TP8.1
SWDIO2: J27.23, J30.2, TP12.1
TX1-DFU_RX-FC0-PLEX: J6.6, U1.P1
TX1-DFU_RX-FC0-PLEX1: J21.6, U8.P1
TX1-DFU_RX-FC0-PLEX2: J33.6, U13.P1
TX1-DFU_RX-FC1-PLEX: J7.6, U1.P2
TX1-DFU_RX-FC1-PLEX1: J22.6, U8.P2
TX1-DFU_RX-FC1-PLEX2: J34.6, U13.P2
TX1-PROCESSOR: J1.17, U1.P4
TX1-PROCESSOR1: J15.17, U8.P4
TX1-PROCESSOR2: J27.17, U13.P4
TX1-PROCESSOR-PLEX: J6.15, U1.P3
TX1-PROCESSOR-PLEX1: J21.15, U8.P3
TX1-PROCESSOR-PLEX2: J33.15, U13.P3
TX2-PROCESSOR: J1.22, J7.15
TX2-PROCESSOR1: J15.22, J22.15
TX2-PROCESSOR2: J27.22, J34.15
VCC: 5V_MEAS.1, 5V_MEAS.3, C2.1, D5.C, J6.72, J6.74, J7.72, J7.74, Q1.2, R4.2, U4.1
VCC1: 5V_MEAS1.1, 5V_MEAS1.3, C16.1, D10.C, J21.72, J21.74, J22.72, J22.74, Q3.2, R33.2, U10.1
VCC2: 5V_MEAS2.1, 5V_MEAS2.3, C25.1, D16.C, J33.72, J33.74, J34.72, J34.74, Q5.2, R51.2, U15.1
VIN: BYP.2, C3.1, D5.A, F2.2, J1.9, Q1.1, R5.1, R6.2, R8.2, R10.2, TP4.1, U2.4
VIN1: BYP1.2, C9.1, D10.A, F1.2, J15.9, Q3.1, R17.1, R25.2, R26.2, R28.2, TP7.1, U6.4
VIN2: BYP2.2, C19.1, D16.A, F3.2, J27.9, Q5.1, R37.1, R43.2, R44.2, R46.2, TP11.1, U11.4
VIN/1: J15.49, R24.2, R25.1
VIN/2: J27.49, R42.2, R43.1
VIN/3: J1.49, R7.2, R10.1
V_BATT: C4.1, J8.2, J11.2, Q1.3, TP3.1, U2.3
V_BATT1: C10.1, J16.2, J24.2, Q3.3, TP6.1, U6.3
V_BATT2: C20.1, J28.2, J36.2, Q5.3, TP10.1, U11.3
V_USB: BYP.1, F2.1, J3.VBUS1, J3.VBUS2, U3.5
V_USB1: BYP1.1, F1.1, J17.VBUS1, J17.VBUS2, U9.5
V_USB2: BYP2.1, F3.1, J29.VBUS1, J29.VBUS2, U14.5

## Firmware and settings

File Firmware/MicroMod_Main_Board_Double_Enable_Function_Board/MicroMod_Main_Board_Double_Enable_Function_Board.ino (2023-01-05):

/******************************************************************************

  WRITTEN BY: Ho Yun "Bobby" Chan
  @ SparkFun Electronics
  UPDATED: 1/3/2023
  DATE: 10/19/2021
  GITHUB REPO: https://github.com/sparkfun/SparkFun_MicroMod_Main_Board_Double
  DEVELOPMENT ENVIRONMENT SPECIFICS:
    Firmware developed using Arduino IDE v1.8.12

  ========== DESCRIPTION==========
  This example code toggles the Function Board's AP2112 3.3V voltage
  regulator's enable pin. The Function Boards built-in power LED should blink.
   This example is based on Arduino's built-in Blink Example:

      https://www.arduino.cc/en/Tutorial/BuiltInExamples/Blink

  Note that this example code uses the MicroMod Main Board - Double. The MicroMod
  Main Board - Single routes the PWR_EN0 pin slightly different for the
  function board. 

  ========== HARDWARE CONNECTIONS ==========
  MicroMod Artemis Processor Board => MicroMod Main Board - Double => Function Boards

  Feel like supporting open source hardware?
  Buy a board from SparkFun!
       MicroMod Artemis Processor Board - https://www.sparkfun.com/products/16401
       MicroMod Main Board - Double - https://www.sparkfun.com/products/20595
       MicroMod Environmental Function Board - https://www.sparkfun.com/products/18632

  LICENSE: This code is released under the MIT License (http://opensource.org/licenses/MIT)

******************************************************************************/

/*Define the power enable pins for the processor board with SDIO_DATA2 and SDIO_DATA1.
  Depending on the processor board, the Arduino pin may be different. 

  Note: Certain Processor Boards like the Artemis have more than one pin available 
        to control the Function Board's voltage regulator (e.g. SDIO_DATA2 and G5).
        SAMD51, ESP32, and STM32 Processor Board pins do not have SDIO_DATA2, so
        users will need to reference the Processor Pin G5. Below are a few examples. */

//==========ARTEMIS==========
// We suggest flipping the switch to the G5 PROC and G6 PROC. The volrage regulators will work reguardless
// since SDIO_DATA2 and SDIO_DATA1 are connected regardless of what side the switch is on.
// Function Board 0's "PWR_EN0" pin <= MicroMod Main - Double SDIO_DATA2 => Artemis Processor Board (D4)  
#define PWR_EN0 4
// Function Board 1's "PWR_EN1" pin <= MicroMod Main - Double SDIO_DATA1 => Artemis Processor Board (D26)
#define PWR_EN1 26

// Make sure switch is flipped over to the EN0 ALT and & EN1 ALT. 
// Alternative option that does the same thing. Make sure to just choose one for PWR_EN0 and PWR_EN1.
// Function Board 0's "PWR_EN0" pin <= MicroMod Main - Double G5 => Artemis Processor Board (A29)
//#define PWR_EN0 29
// Function Board 1's "PWR_EN0" pin <= MicroMod Main - Double G6 => Artemis Processor Board (D14)
//#define PWR_EN1 14


//==========TEENSY==========
// We suggest flipping the switch to the G5 PROC and G6 PROC. The volrage regulators will work reguardless
// since SDIO_DATA2 and SDIO_DATA1 are connected regardless of what side the switch is on.
// Function Board 0's "PWR_EN0" pin <= MicroMod Main - Double SDIO_DATA2 => Teensy Processor Board (D39)
//#define PWR_EN0 39
// Function Board 1's "PWR_EN1" pin <= MicroMod Main - Double SDIO_DATA1 => Teensy Processor Board (D34)
//#define PWR_EN1 34

// Make sure switch is flipped over to the EN0 ALT and & EN1 ALT. 
// Alternative option that does the same thing. Make sure to just choose one for PWR_EN0 and PWR_EN1
// Function Board 0's "PWR_EN0" pin <= MicroMod Main - Double G5 => Teensy Processor Board (45)
//#define PWR_EN0 45
// Function Board 1's "PWR_EN1" pin <= MicroMod Main - Double G6 => Teensy Processor Board (6)
//#define PWR_EN1 6



//Note: The SAMD51, ESP32, and STM32 Processor Board Pins do not have SDIO_DATA2 and SDIO_DATA1.

//==========SAMD51==========
// Make sure switch is flipped over to the EN0 ALT and & EN1 ALT. 
// Function Board 0's "PWR_EN0" pin <= MicroMod Main - Double G5 => SAMD51 Processor Board (D7)
//#define PWR_EN0 7
//Function Board 1's"PWR_EN1" pin <= MicroMod Main - Double G6 => SAMD51 Processor Board (D8)
//#define PWR_EN1 8


//==========ESP32==========
// Make sure switch is flipped over to the EN0 ALT and & EN1 ALT. 
// Function Board 0's "PWR_EN0" pin <= MicroMod Main - Double G5 => ESP32 Processor Board (32)
//#define PWR_EN0  32
// Function Board 1's"PWR_EN1" pin <= MicroMod Main - Double G6 => ESP32 Processor Board (33)
//#define PWR_EN1  33



void setup() {
  // initialize the digital pins as an output.
  pinMode(PWR_EN0, OUTPUT); 
  pinMode(PWR_EN1, OUTPUT);

}



void loop() {

  digitalWrite(PWR_EN0, HIGH); // turn the 3.3V regulator on (HIGH is the voltage level)
  digitalWrite(PWR_EN1, HIGH); // turn the 3.3V regulator on (HIGH is the voltage level)
  delay(5000);                 // wait for a few seconds to do something with the function boards 

  digitalWrite(PWR_EN0, LOW);  // turn the 3.3V regulator off by making the voltage LOW
  digitalWrite(PWR_EN1, LOW);  // turn the 3.3V regulator off by making the voltage LOW
  delay(5000);                 // wait for a few seconds before turning function boards back on

}

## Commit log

2021-08-17 Initial Commit (post-prototype, pre finalized-for-REDs)
    [Motherboard.GBL, Motherboard.GBO, Motherboard.GBP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]
2021-08-31 Adds second standoff for qwiic boards, attaches VIN net to processor connector
    Deletes second page in schematic
    [Motherboard.brd, Motherboard.sch]
2021-08-31 Fixes trace routing
    * Removes
    [Motherboard.brd, Motherboard.sch]
2021-08-31 Adds silk, removes "VIN/VUSB" jumper
    [Motherboard.brd, Motherboard.sch]
2021-08-31 Double routes power enable for ESP32 processor boards
    [Motherboard.brd, Motherboard.sch]
2021-08-31 Rename polygon to VIN to match the trace, approves some overlap errors
    [Motherboard.brd]
2021-09-02 Adds 2 pin dip switch for charge selection, switches diode to PCHN MOSFET to VBAT net
    * Adds better silk
    * Adds charge selection table to schematic
    * Moves standoffs around
    [Motherboard.brd, Motherboard.sch]
2021-09-02 Moved something in the schematic
    [Motherboard.sch]
2021-09-02 Adds qwiic standoff silk
    [Motherboard.brd]
2021-09-02 Replace MOSFET with another one
    [Motherboard.brd, Motherboard.sch]
2021-09-03 Adds 10k pull down to PCHAN MOSFET
    [Motherboard.brd, Motherboard.sch]
2021-09-07 Adds jumpers to route power enable pins to G0/G1 for processors that don't have those nets routed
    * Adds silk to added jumpers
    * Adds PROD-ID to function board connectors
    [Motherboard.brd, Motherboard.sch]
2021-09-08 Adds PTH headers for shunt selectable settings on G0 and G1 for PWR_EN0 and PWR_EN1 respectively
    [Motherboard.brd, Motherboard.sch]
2021-09-08 Revert "Adds PTH headers for shunt selectable settings on G0 and G1 for PWR_EN0 and PWR_EN1 respectively"
    This reverts commit ddf80de5a278d55282677fb1bccc97569ea5aff3.
    [Motherboard.brd, Motherboard.sch]
2021-09-08 Recreates changes from last change but instead moves jumpers to nets G5/G6
    [Motherboard.brd, Motherboard.sch]
2021-09-08 Fixes typo
    [Motherboard.sch]
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2021-09-09 Moves labels, seeds more vias
    [Motherboard.brd]
2021-09-10 Adds labels to pwr-enable selection headers, moves SD card slightly towards center of board
    [Motherboard.brd]
2021-09-10 ...and again moves SD card slightly upward
    [Motherboard.brd]
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2021-09-10 Renames eagle files - panelizes new design
    [Main Board - Double-Panel.GBL, Main Board - Double-Panel.GBO, Main Board - Double-Panel.GBP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]
2021-09-10 Adds new panel that is a single column of three.
    [Main Board - Double-Panel.GBL, Main Board - Double-Panel.GBO, Main Board - Double-Panel.GBS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]
2021-10-11 Changes power to Function Boards @ VCC to VCC rather than VIN
    [Main Board - Double.brd, Main Board - Double.sch]
2021-10-11 Adds two GND vias
    [Main Board - Double.brd]
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2021-10-22 Replaces schottky diode
    [Main Board - Double.brd, Main Board - Double.sch]
2021-11-03 Updates Function board symbol, fixes some text explaining two pin jumper, corrects charging current.
    [Main Board - Double.brd, Main Board - Double.sch]
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2021-11-11 Updates the design to use the Micromod-function device in the official SFE Eagle Libs
    [Main Board - Double.brd, Main Board - Double.sch]
2022-06-22 Changes resistor values on LEDs, updates plexing symbol, increases capacitor value on microSD
    * Adds NC jumper to shield pin on USB-C
    [Main Board - Double.brd, Main Board - Double.sch]
2022-06-22 Updates the symbol for the multiplexer and net names
    [Main Board - Double.brd, Main Board - Double.sch]
2022-06-22 Double routes chip select and analog one
    [Main Board - Double.brd, Main Board - Double.sch]
2022-06-22 Adds default state to plexer, includes new function card symbol with new plexing control pins
    [Main Board - Double.brd, Main Board - Double.sch]
2022-06-22 Fixes swapped RX/TX
    [Main Board - Double.brd, Main Board - Double.sch]
2022-06-22 Adds pull up resistors to i2c data lines
    [Main Board - Double.brd, Main Board - Double.sch]
2022-06-22 Updates cream and stop layers on uart-multiplexer
    * Updates schematic
    * Routes pullup jumper
    [Main Board - Double.brd, Main Board - Double.sch]
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2022-06-28 Updates design with new dip switch
    [Main Board - Double.brd, Main Board - Double.sch]
2022-06-29 Large rework in which many of the traces were routed to leave more space between them.
    [Main Board - Double.brd, Main Board - Double.sch]
2022-06-29 Routes more air wires, cleans up DRC
    [Main Board - Double.brd]
2022-06-29 Routes the last of the iar wires
    [Main Board - Double.brd]
2022-06-29 Flipped the switches around for better labels
    [Main Board - Double.brd]
2022-06-29 Adds vias, moves traces for ground pour
    [Main Board - Double.brd]
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2022-06-29 Approves various wire stub errors
    [Main Board - Double.brd]
2022-06-30 Fixes some vias, deletes value of jumper
    [Main Board - Double.brd, Main Board - Double.sch]
2022-06-30 Fixes ground pour in areas throughout, adds vias, updates net positioning and text layout in schematic
    * Increases cap on output of VREG
    [Main Board - Double.brd, Main Board - Double.sch]
2022-07-01 Improves routing, snaps many parts to a much more sensible grid, removes some caps on INPUT and OUTPUT of VREG that were not necessary
    * Adds another MEAS Jumper for 5V side
    * Removes selection on charge circuit (500mA now only)
    * Fixes chip select not being double routed corectly
    [Main Board - Double.brd, Main Board - Double.sch]
2022-07-01 Many more grid improvements
    [Main Board - Double.brd, Main Board - Double.sch]
2022-07-07 Adds ESD protection to USB lines, replaces switches with cheaper more widely available ones
    [Main Board - Double.brd, Main Board - Double.sch]
2022-07-08 Adds new VREG, new VREG added to control 3.3V @ Qwiic Connectors, moves i2c pullup jumper (connected to 3v3 not 3v3_Qwiic)
    [Main Board - Double.brd, Main Board - Double.sch]
2022-07-11 Adds silk, updates alignment of existing silk that was not replaced, updates landing pads for new mux part
    [Main Board - Double.brd, Main Board - Double.sch]
2022-07-11 Updates text in schematic
    [Main Board - Double.sch]
2022-07-11 Updates device name and removes value from new VREG
    [Main Board - Double.brd, Main Board - Double.sch]
2022-07-11 Fixes ESD Diode
    [Main Board - Double.brd, Main Board - Double.sch]
2022-07-11 Adds ICs necessary for discrete UART switcher to library
    * Places new parts into "discrete" version of the main board.
    [Main Board - Double _Discrete.brd, Main Board - Double _Discrete.sch, Main Board - Double.brd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]
2022-07-11 Matches length of D+ and D-
    [Main Board - Double _Discrete.brd, Main Board - Double _Discrete.sch, Main Board - Double.brd]
2022-07-11 Adds Gerbers for Main Board (non-discrete)
    [Main Board - Double.GBL, Main Board - Double.GBO, Main Board - Double.GBP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]
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2022-07-15 Fixes vias that are intended to be ground to be ground
    [Main Board - Double.brd]
2022-08-18 Adds a totally different design - designed in Fusion, pushed back here to fix silk
    [Main Board - Double v3.brd, Main Board - Double v3.sch]
2022-08-18 Changes resistor divider jumper name and qwiic_led jumper name
    [Main Board - Double v3.brd, Main Board - Double v3.sch]
2022-08-18 Clears overlap DRC errors
    [Main Board - Double v3.brd]
2022-08-19 Removes old designs, updates polygons
    * Updates silk
    * Uses VIN as power supply to battery charger
    * Fixes PCH Mosfet
    [Main Board - Double _Discrete.brd, Main Board - Double _Discrete.sch, Main Board - Double v3.brd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]
2022-08-19 Fixes airwire
    [Main Board - Double v3.brd]
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2022-08-31 Moves I2C pullups to make space for silk
    [SparkFun_Main_Board_Double_v20.brd, SparkFun_Main_Board_Double_v20.sch]
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2022-10-26 Adds new version of main board double
    * The chip selection switch was not routed correctly on the previous version
    [SparkFun_Main_Board_Double_v22.brd, SparkFun_Main_Board_Double_v22.sch]
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2022-10-28 Adds notch for lipo battery, moves VBAT test point
    [SparkFun_Main_Board_Double_v22.brd]
2022-10-31 Fixes minor width DRC errors
    [SparkFun_Main_Board_Double_v22.brd]
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

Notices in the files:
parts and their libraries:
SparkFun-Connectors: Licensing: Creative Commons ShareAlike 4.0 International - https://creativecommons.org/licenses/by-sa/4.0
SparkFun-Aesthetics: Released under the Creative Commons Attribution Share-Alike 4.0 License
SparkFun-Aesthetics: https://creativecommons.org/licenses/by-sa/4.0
